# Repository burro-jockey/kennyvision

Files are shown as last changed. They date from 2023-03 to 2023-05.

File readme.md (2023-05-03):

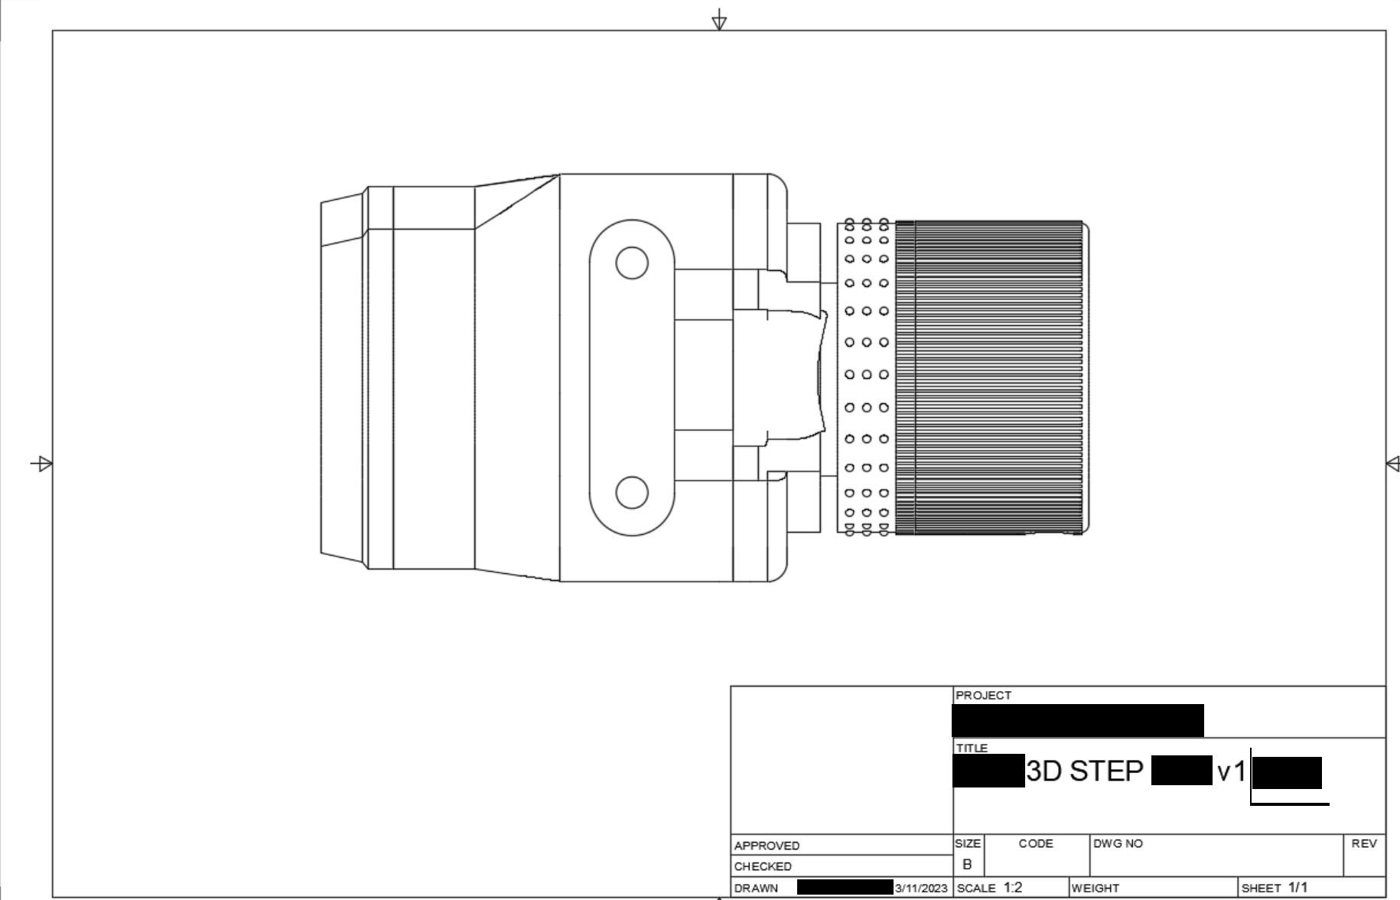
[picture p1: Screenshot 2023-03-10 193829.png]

# Im not sure what to call this project
This is fork (for lack of a better term) of a beta made by s3ktor. 

The purpose of this project was to create a more modular platform for use in testing. There are so many different options it makes it hard decide which is the best. With spec sheets often sketchy, some brave soul will often have to just buy the thing to try it out. 

This project aims to make it easy to test multiple configurations of both input and output.
For example, I currently can switch to these inputs:
- hdmi capture card
- runcam
- foxeer
- raspberry pi zero
- drone cam  *<i>soon</i>

I can also swap outputs (more on this later?)

If you're a more visual learner it might help to look at the wip building instructions: [here](https://github.com/burro-jockey/kennyvision/blob/main/Page%201-merged.pdf)
## The basics

*Most diy night vision devices have two primary components.
- a display
- a camera

Most projects assume that their solution is the best which is cool, and maybe even correct but depending on regional availability and cost, can make contribution harder than it has to be. An additional consequence of this direction is that most designs have wiring internally. as to be more low-drag. This makes it difficult to change inputs or test other inputs. Our approach differs by moving the connection externally. In doing this you can take advantage of the digital nature of your night vision, by being able to easily record, change and eventually add more information to your nvgs.

The key to the solution is the  [5 Pin Electrical Connector 24AWG IP65 Male & Female Connector 15mm Nut Small Size](https://www.amazon.com/Hysmigor-Electrical-Connector-Extension-Outdoor/dp/B09NDWYJG8?th=1) 
Connectors

Since analog video only requires one wire, it is very easy to do the wiring for most analog video. Additionally, this project currently only uses three of the five wires - the other two being ground and power. 
Using these (or another type of) connectors you can quickly hot swap video by unscrewing and pulling apart. You can also you add male and female to make an inline recorder or caster. its water proof and makes wiring so mf simple anyone could do it. If you must make it high speed low drag, you can always zip-tie or one wrap the cable to the monocular.

## Rough parts list:
Thanks to s3ktor for putting this together
 -  9x  ~10mm M4 thread insert
 -  6x  16mm M4 Bolts 
 - 1x  [Runcam Night Eagle 3](https://www.amazon.com/RunCam-Night-Camera-1000TVL-Support/dp/B09JVG2D5W?th=1)
 - 1x [Foxeer Micro Night Cat 3](https://www.amazon.com/Camera-Foxeer-1200TVL-Starlight-Version/dp/B08YJM6BY2/r%20ef=asc_df_B08YJM6BY2/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) 
 - 1x [Eisco Labs Double Convex 38mm Lens](https://www.amazon.com/Eisco-Labs-Glass-Lenses-Diameter/dp/B01F9KXRX2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) 
- 1x [NTSC/PAL 1.5” Display](https://www.adafruit.com/product/910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) 
- 1x [5 Pin Electrical Connector 24AWG IP65 Male & Female Connector 15mm Nut Small Size](https://www.amazon.com/Hysmigor-Electrical-Connector-Extension-Outdoor/dp/B09NDWYJG8?th=1) 

## Housing Info
Currently the housing is intended to be very modular, almost certainly at the cost of functionality. 

There are 2 primary modules which are the display and input source (camera).

The camera module is designed to thread into the housing. 

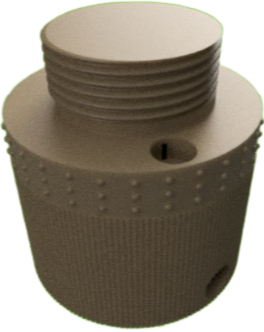
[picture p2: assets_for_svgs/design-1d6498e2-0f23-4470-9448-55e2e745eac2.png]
A low quality render of the camera module


I'm really not sure about the practical strength of this method but it works good so far.

Here is the display module.

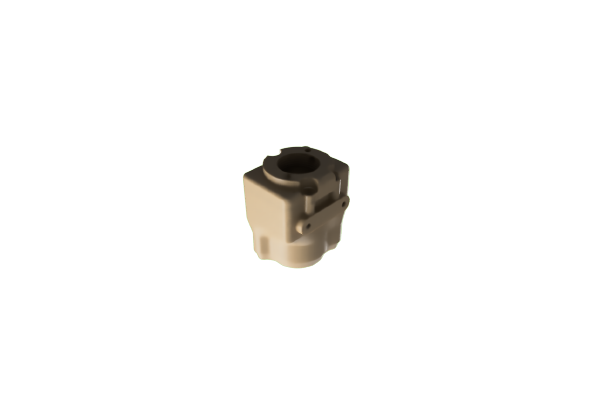
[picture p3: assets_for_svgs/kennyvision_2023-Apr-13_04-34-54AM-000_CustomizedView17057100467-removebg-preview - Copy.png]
render of display module


as you can see if you are in the beta I completely stole the geometry of this. That way it can use the same display and lens as the beta while also being slightly easier to print in my opinion. We can also make this water tight easily using this a 1-3/16th(I.D.),  1/16th wide o-ring. (Thanks Ace)

Basically these 2 connect and make this device. Which is your night vision.

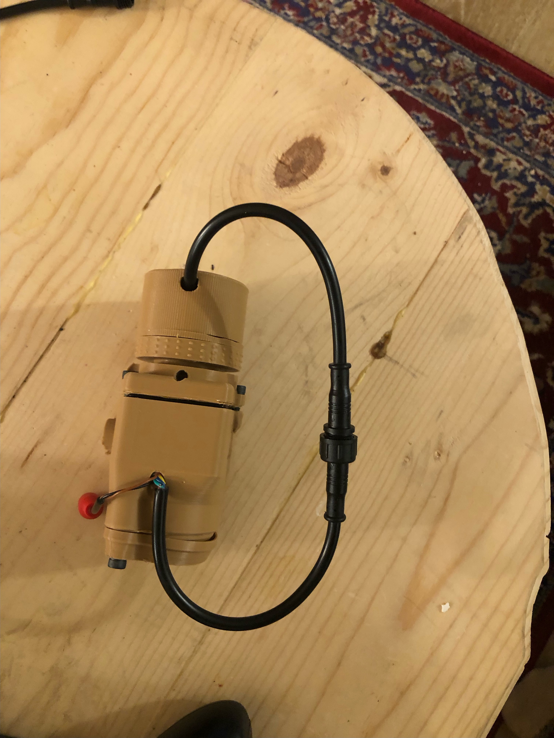
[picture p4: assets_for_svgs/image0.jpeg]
crude night vision device


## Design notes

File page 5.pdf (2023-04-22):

x7
7

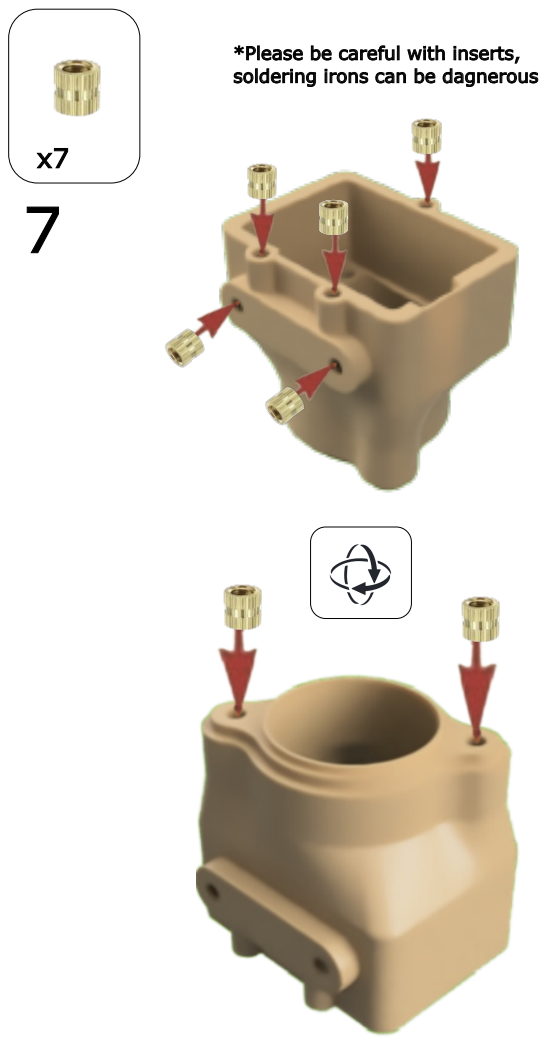
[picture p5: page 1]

*Please be careful with inserts,
soldering irons can be dagnerous

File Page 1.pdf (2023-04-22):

1

x1 | x1

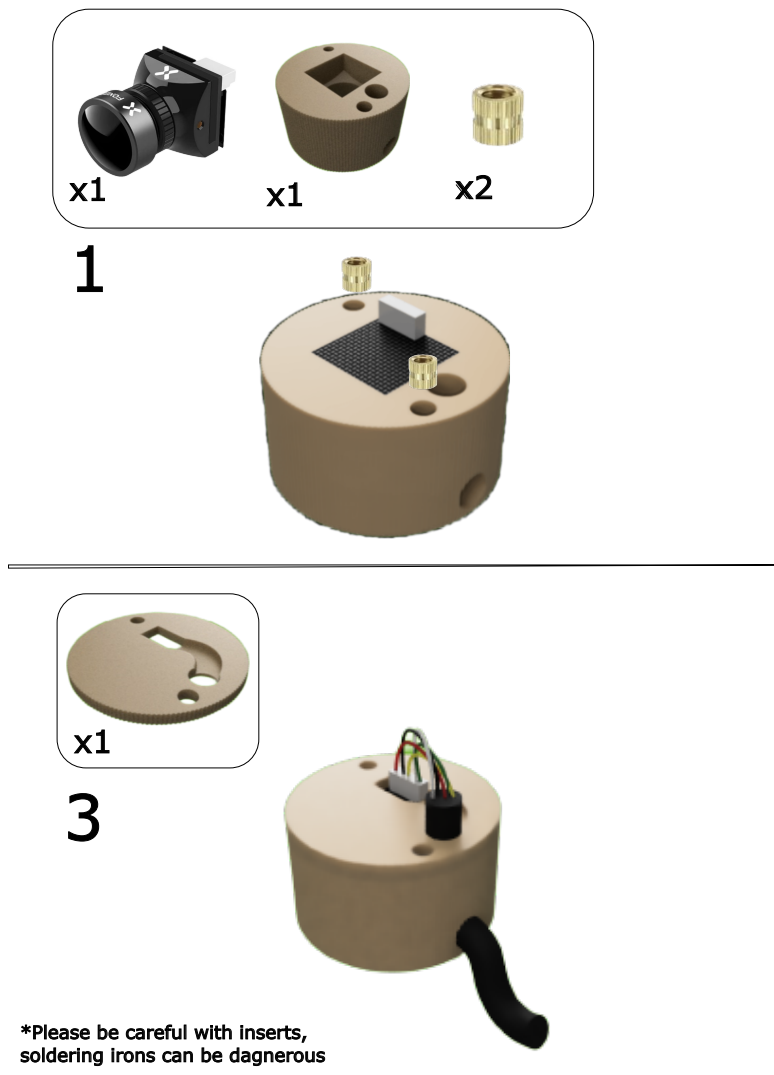
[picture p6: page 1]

*Please be careful with inserts,
soldering irons can be dagnerous

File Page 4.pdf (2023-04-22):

6

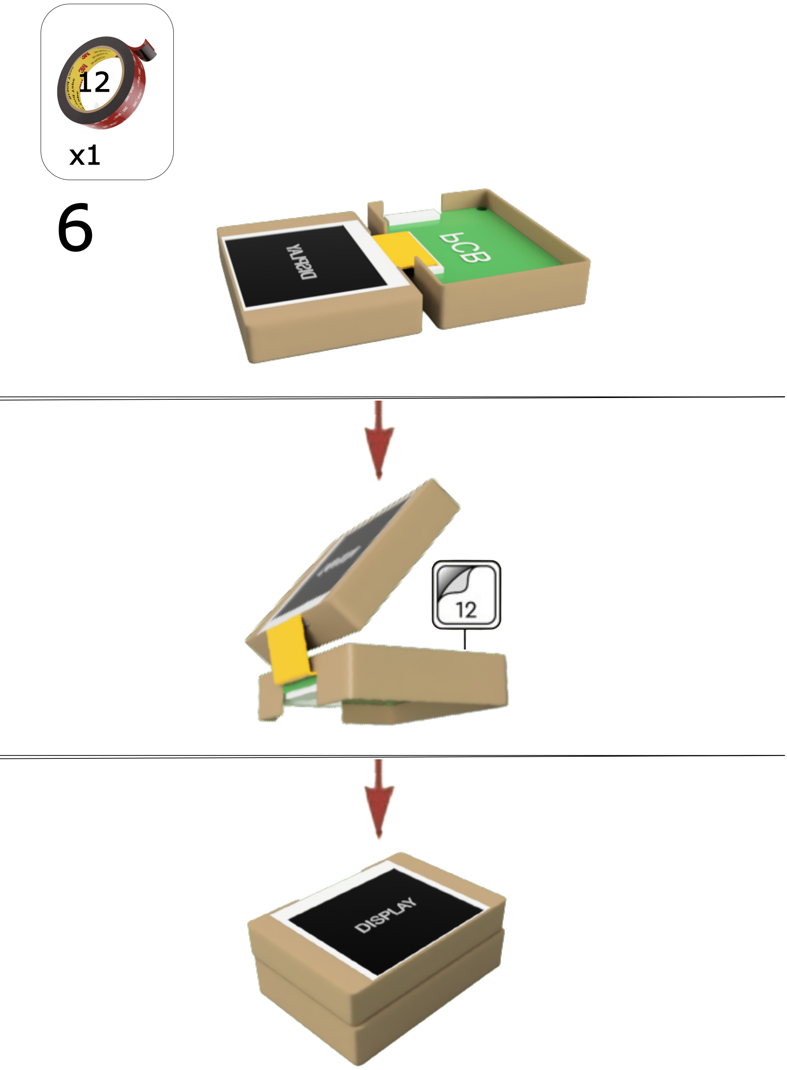
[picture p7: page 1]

x1

12

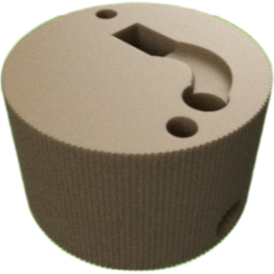
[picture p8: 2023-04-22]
assets_for_svgs/design-a9bf3d48-4b37-41bc-bd95-cec1d62aba45.png

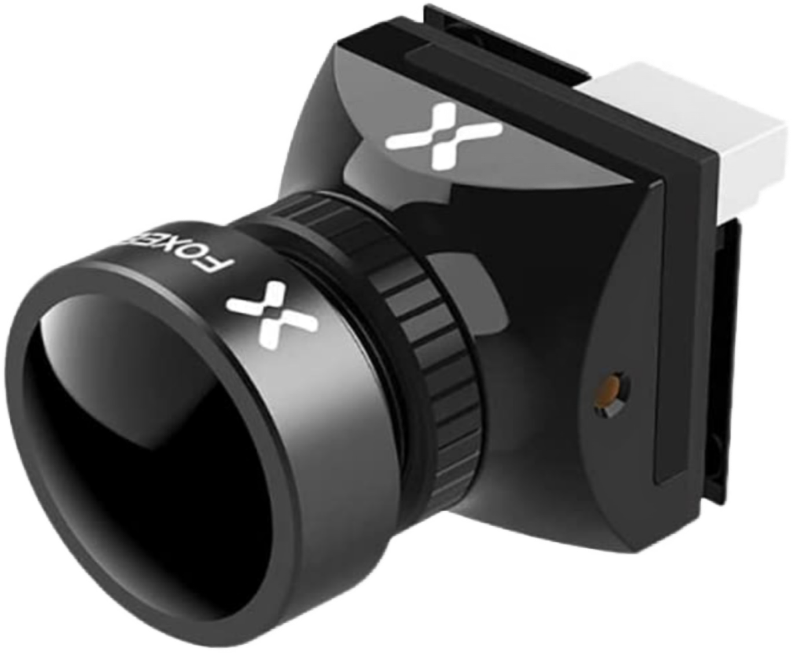
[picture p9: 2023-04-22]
assets_for_svgs/design-511578bc-40f1-4768-bbd8-994f969f9da6 - Copy.png

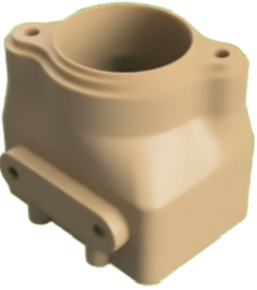
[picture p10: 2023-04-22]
assets_for_svgs/design-817d46e4-0363-4350-8838-6e425cc4b8b4 - Copy.png

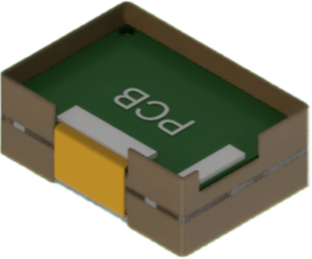
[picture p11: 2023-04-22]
assets_for_svgs/design-9cfaff9e-8191-41d2-a9c9-b75a14ba01a3 - Copy.png

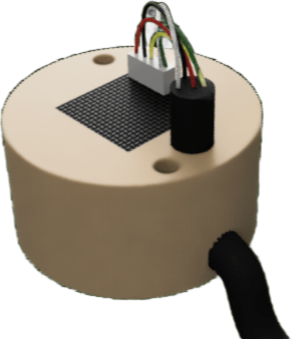
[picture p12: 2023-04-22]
assets_for_svgs/design-e2826244-3ce9-4b5b-be71-0f37165b7497.png

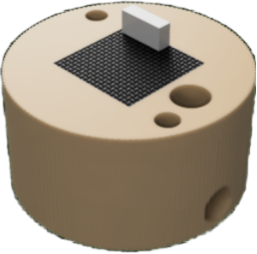
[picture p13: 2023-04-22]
assets_for_svgs/design-17b1d884-e87c-4829-b508-188f45d2d4c3.png

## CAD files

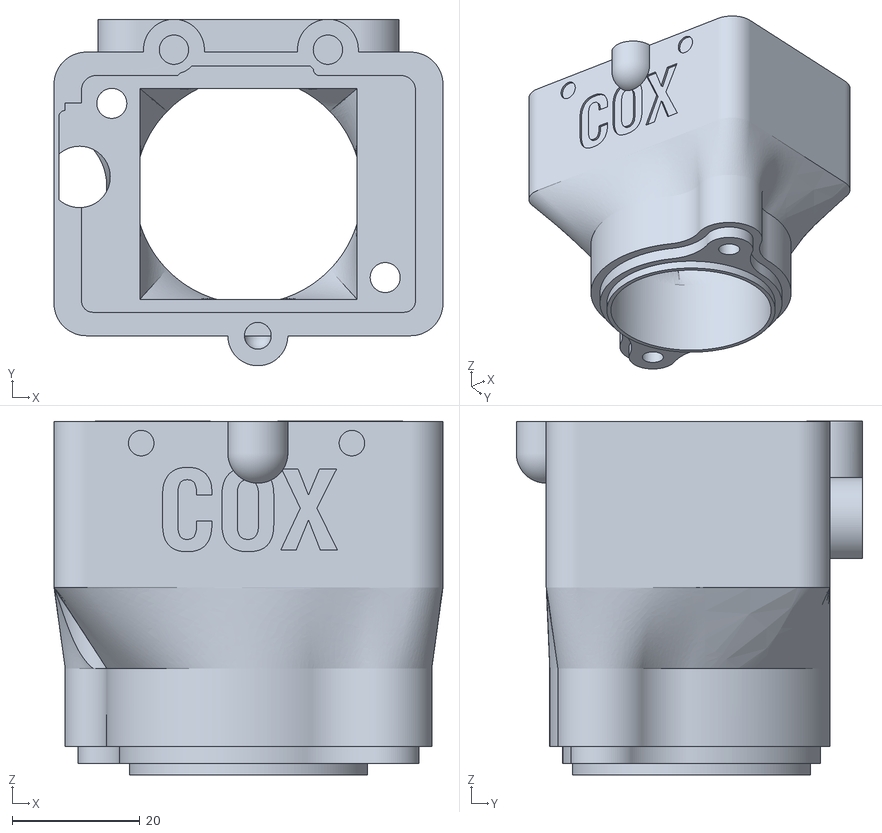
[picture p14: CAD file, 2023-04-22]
main_body.stl
61.0 x 54.3 x 55.4

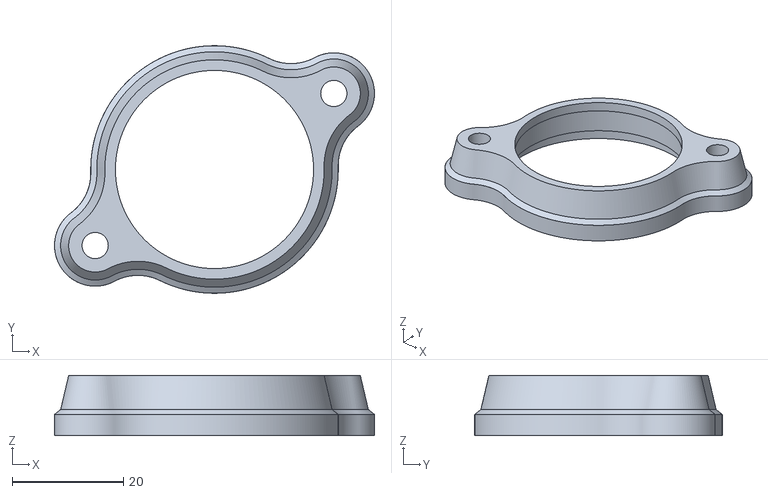
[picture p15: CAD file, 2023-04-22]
lense_holder.stl
57.4 x 44.4 x 10.8

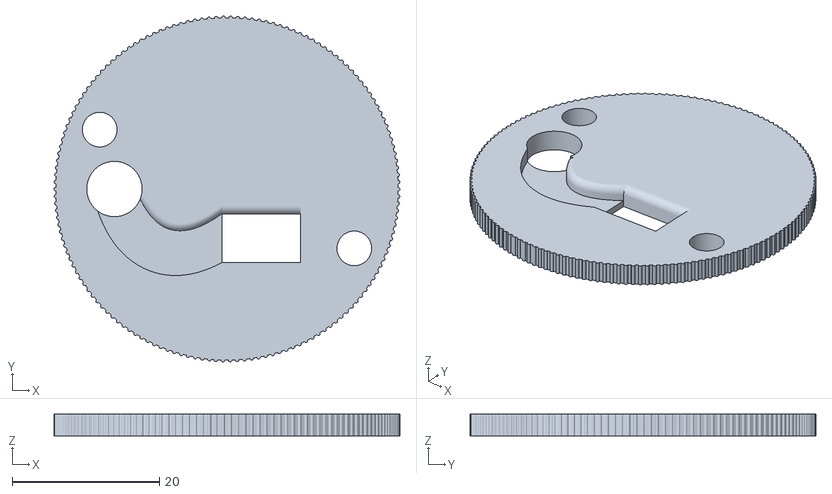
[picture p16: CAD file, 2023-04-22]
middle_piece.stl
46.9 x 46.9 x 2.92

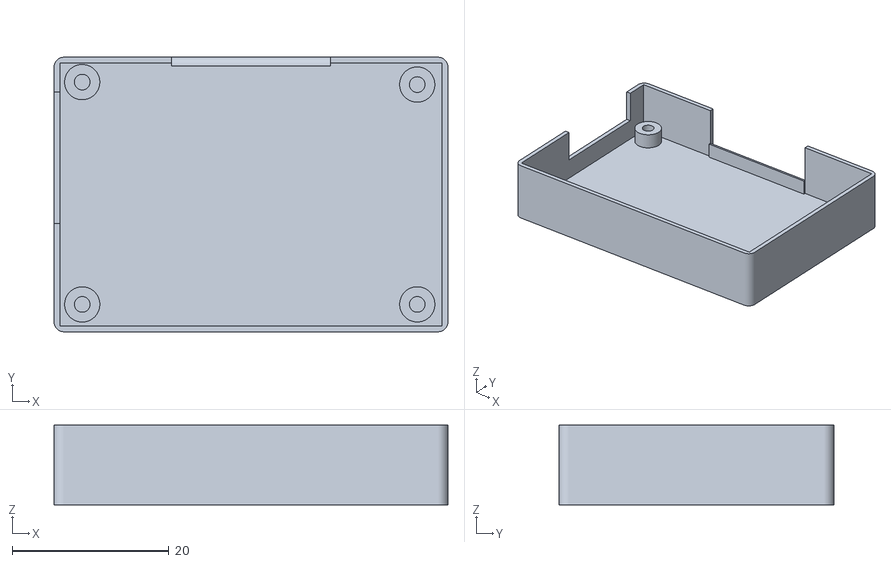
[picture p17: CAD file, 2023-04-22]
pcb_holder.stl
50.3 x 35.1 x 10.2

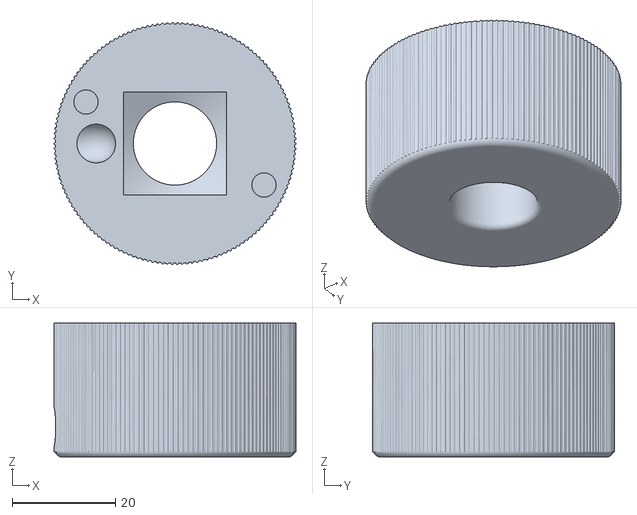
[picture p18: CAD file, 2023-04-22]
cam_mount.stl
46.9 x 46.9 x 26.0

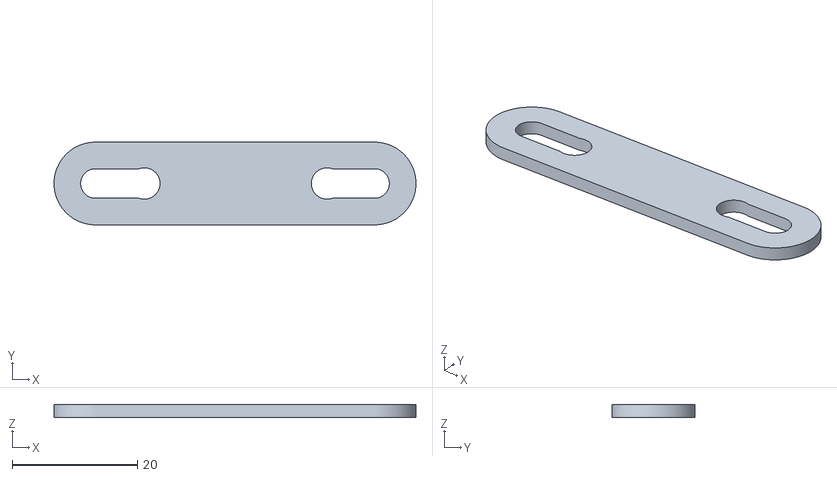
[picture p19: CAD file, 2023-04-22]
riser.stl
57.8 x 13.2 x 2.00

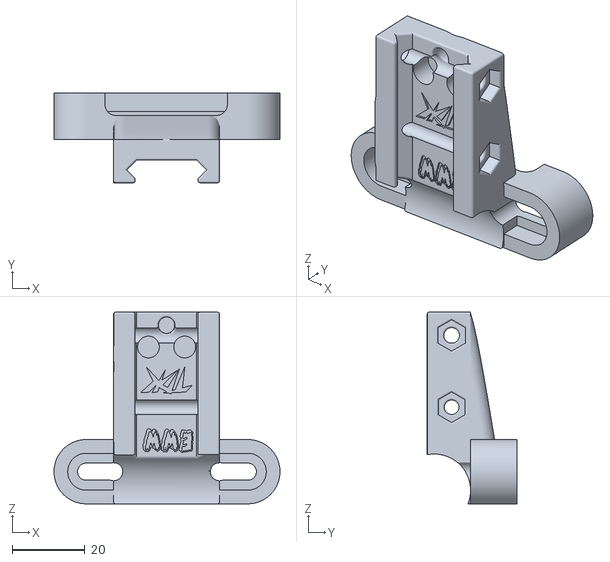
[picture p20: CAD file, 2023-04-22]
rail_mount.stl
62.3 x 24.7 x 52.8

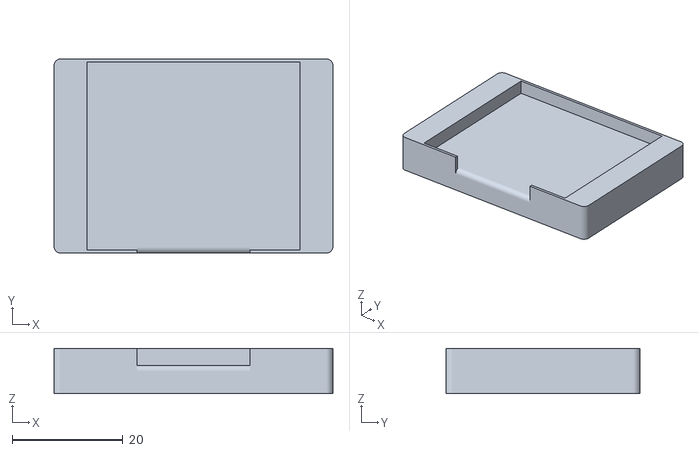
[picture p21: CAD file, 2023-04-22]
screen_holder.stl
50.3 x 35.1 x 8.13

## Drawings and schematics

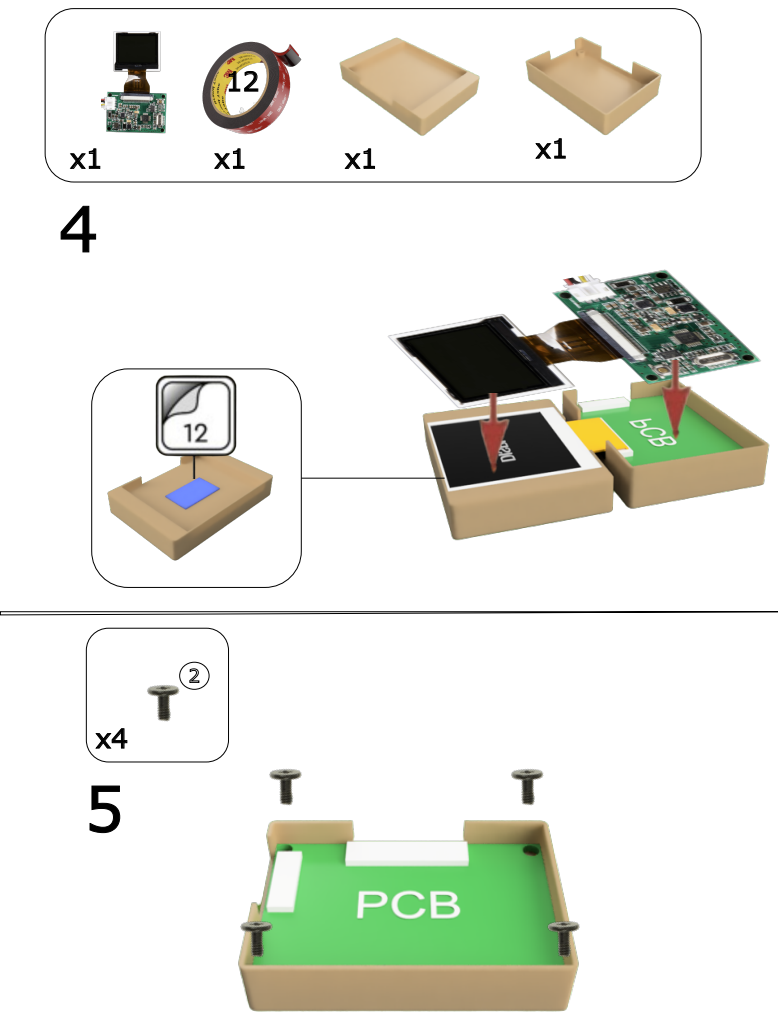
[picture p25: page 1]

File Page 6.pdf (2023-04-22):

8

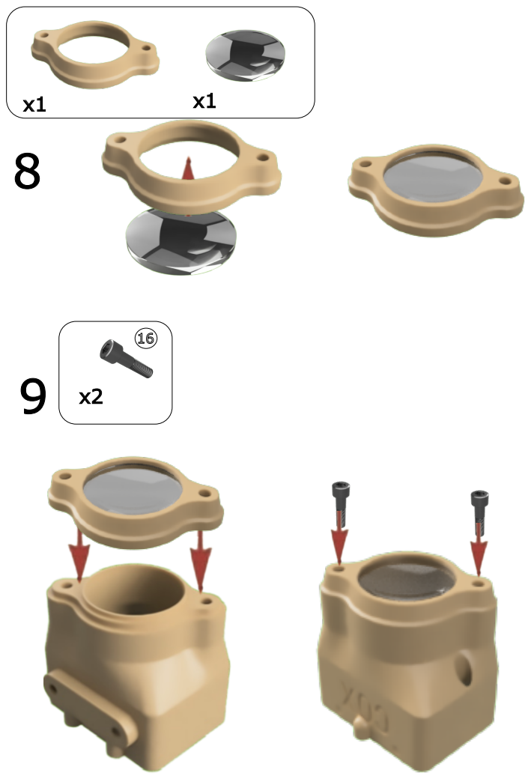
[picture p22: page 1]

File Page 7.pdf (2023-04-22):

1

0

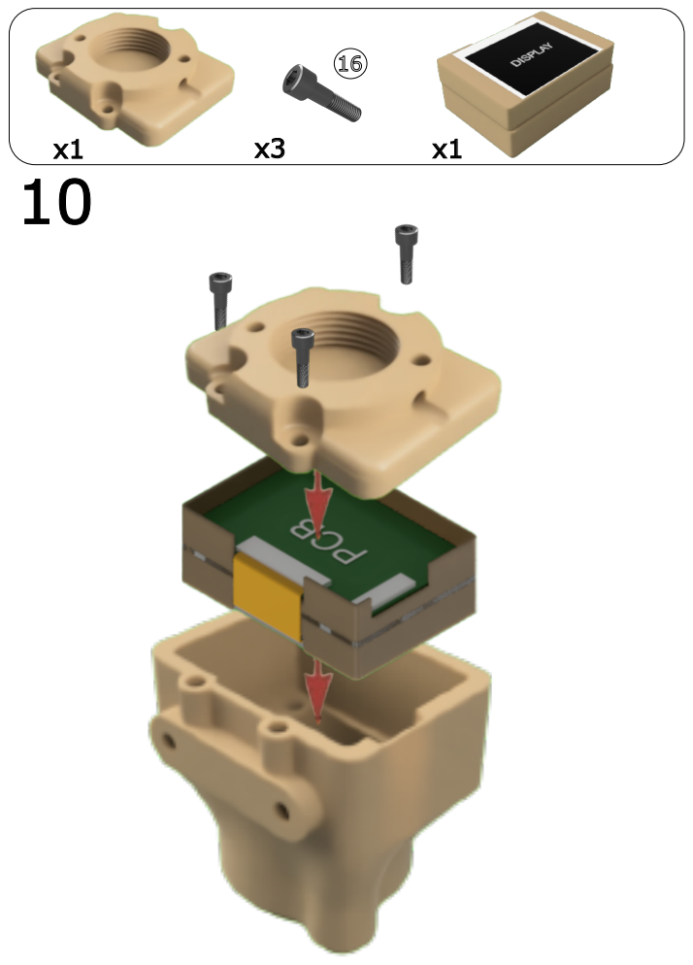
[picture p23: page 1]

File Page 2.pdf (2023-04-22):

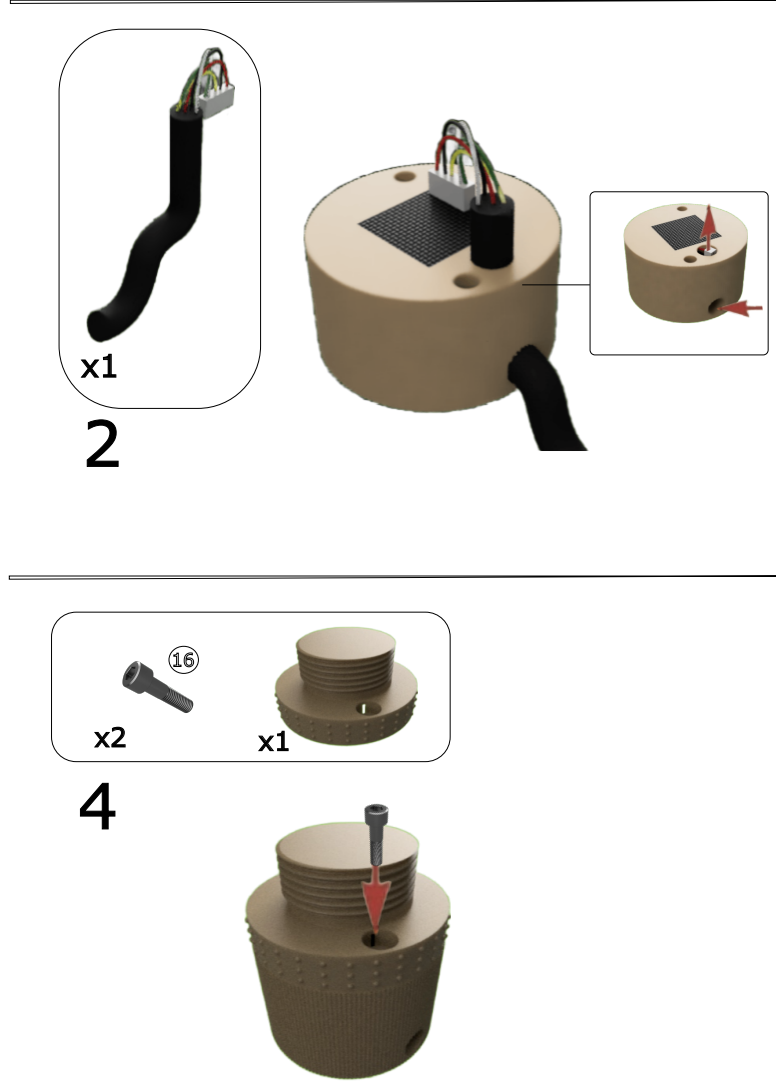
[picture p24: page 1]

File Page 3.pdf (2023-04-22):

4
